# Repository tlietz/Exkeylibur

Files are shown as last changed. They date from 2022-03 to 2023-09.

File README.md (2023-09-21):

# Exkeylibur

```markdown
I froze your switches and made Exkeylibur,
and pushed it onto Github forever.
It stays there like Excalibur,
Are you its Arthur?
Say you are.

Take the cool, dark, steeled board,
Steal it, sheath it, in your workflow.
All would drown their other keebs to be together.
Must they breathe? 'Cause typing feels like heaven.
```

*Based off of ['Excalibur' - by David Brent](https://www.youtube.com/watch?v=634TC7Feku4)*

I would like to thank the honorable [Ferris Sweep](https://github.com/davidphilipbarr/Sweep), for without you, the Exkeylibur would have no pcb layout.

## Prelude

An Exkeylibur is a 36-key, diodeless, wireless-only keyboard with Ferris stagger and a reversible PCB.

An Exkeylibur can be wielded without a sheath, however, you are encouraged to create one.

A promicro, or any other non-wireless microcontroller drop-in for the promicro, is **not** supported. This is because the GPIO pin that would normally go to a TRRS jack
now goes to an extra switch.

## Features

- Wireless only
- No diodes required
- 36 keys
- Reversible PCB
- Ferris stagger
- Choc-spaced

## V2 Changes

- Rotated outer thumb key by 90 degrees to support 1.5u keycap
- Added room to place rubber feet
- Moved home thumb key to be between the two thumb keys of the Ferris Sweep
- Placed reset button in a position that can be easily pressed with finger
- Slightly increased reset button pcb pad spacing to support more button sizes

## Firmware Build Instructions

Edit the `ZMK_PATH`, `MCU`, and `KEEB` variables in `Makefile`

If this is your first time, run `make pristine`.
Next time, you can just do `make`.

The `firmware/` directory will have the left and right firmware files.

The keymap here may change in the future.

## Images

### V2

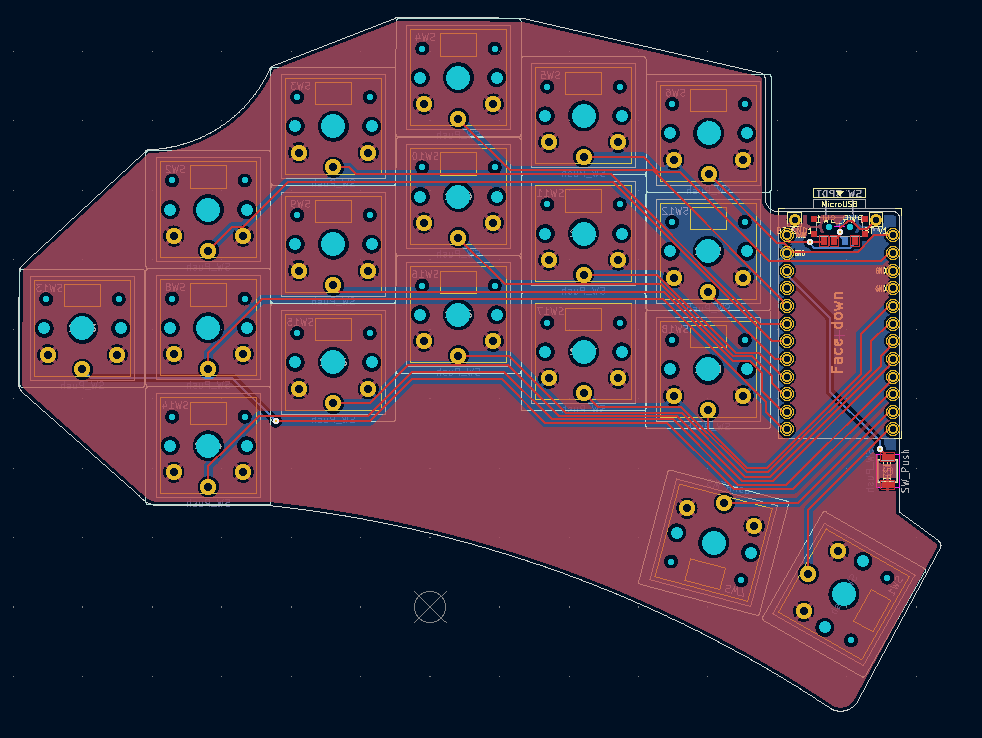
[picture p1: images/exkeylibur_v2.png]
v2


### V1

#### Original

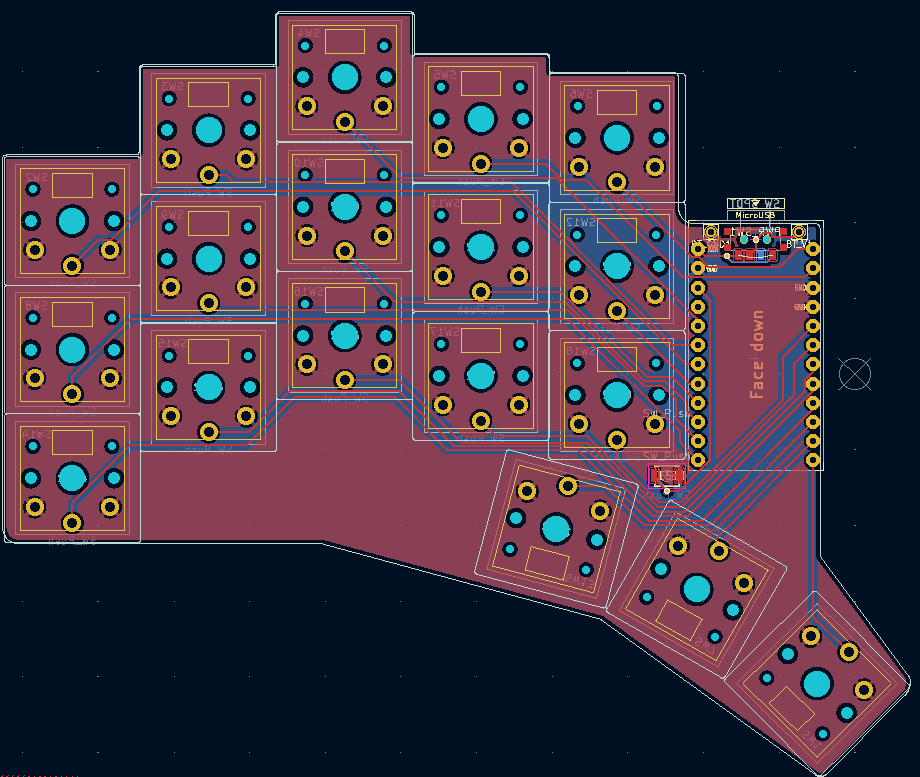
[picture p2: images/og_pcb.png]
original-pcb


#### Hilt

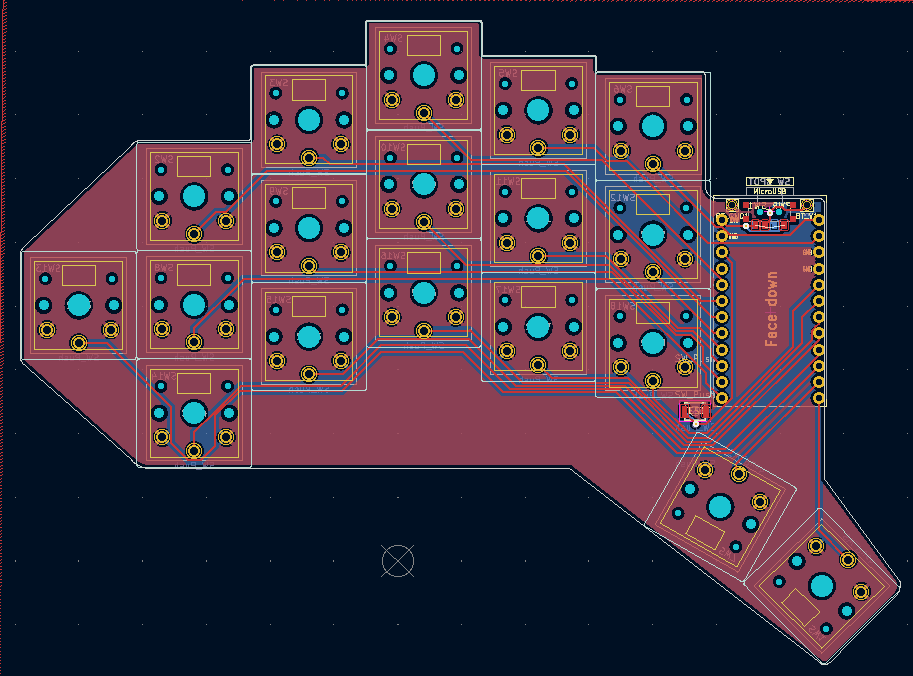
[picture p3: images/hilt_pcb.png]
hilt-pcb


#### Dagger

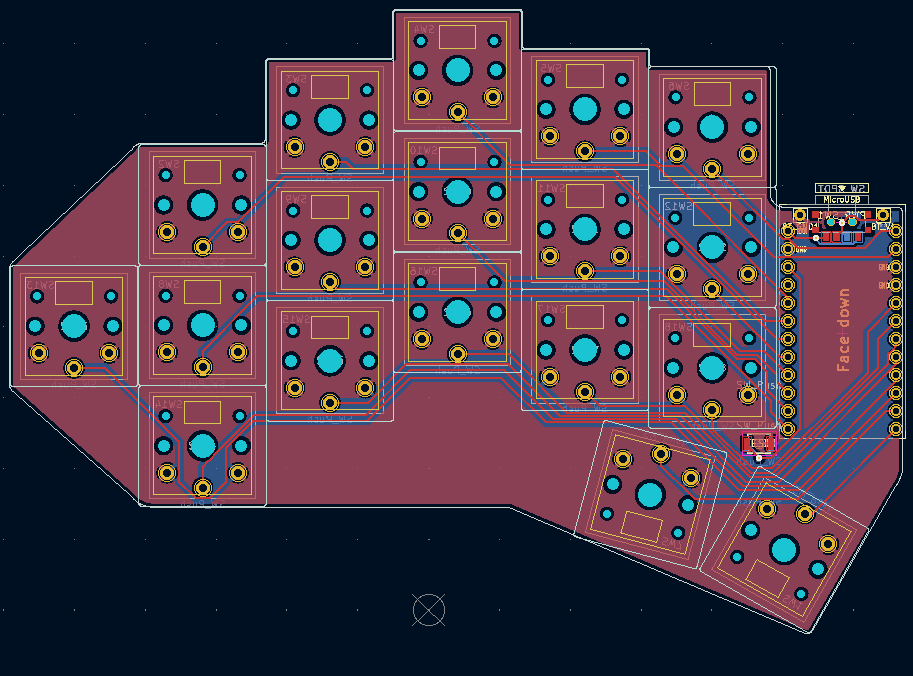
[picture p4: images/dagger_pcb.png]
dagger-pcb


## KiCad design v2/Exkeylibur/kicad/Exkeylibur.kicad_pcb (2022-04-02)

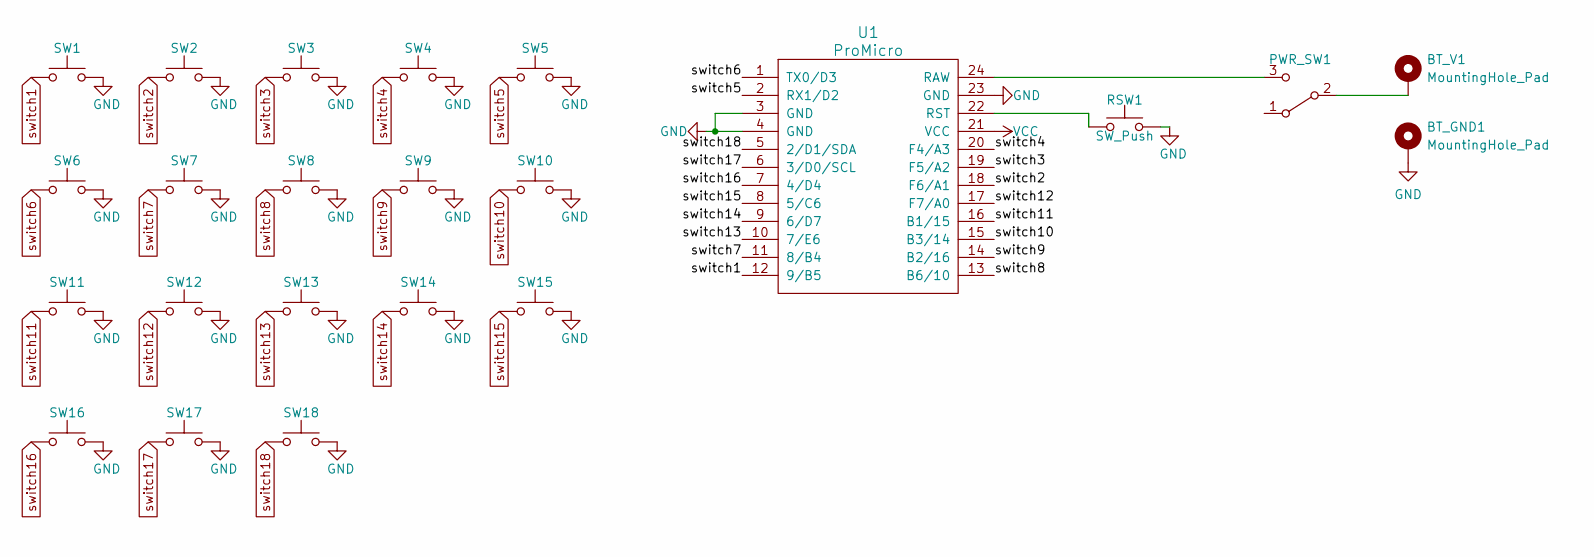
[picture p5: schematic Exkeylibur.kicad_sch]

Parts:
BT_GND1: MountingHole_Pad; bat_gnd_mountingHole
BT_V1: MountingHole_Pad; Bat_MountingHole
PWR_SW1: SW_SPDT; SPDT_C128955
RSW1: SW_Push; reset_switch
SW1, SW2, SW3, SW4, SW5, SW6, SW7, SW8, SW9, SW10, SW11, SW12, SW13, SW14, SW15, SW16, SW17, SW18: SW_Push; choc_switch_reversible
U1: ProMicro; ProMicro_v3_min

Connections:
GND: BT_GND1.1, RSW1.2, SW1.2, SW2.2, SW3.2, SW4.2, SW5.2, SW6.2, SW7.2, SW8.2, SW9.2, SW10.2, SW11.2, SW12.2, SW13.2, SW14.2, SW15.2, SW16.2, SW17.2, SW18.2, U1.3 (GND), U1.4 (GND), U1.23 (GND); also elsewhere on the board
unnamed 1: BT_V1.1, PWR_SW1.2 (B); also elsewhere on the board
unnamed 2: PWR_SW1.3 (C), U1.24 (RAW); also elsewhere on the board
unnamed 3: RSW1.1, U1.22 (RST); also elsewhere on the board
VCC: U1.21 (VCC)
switch1: SW1.1, U1.12 (9/B5)
switch2: SW2.1, U1.18 (F6/A1)
switch3: SW3.1, U1.19 (F5/A2)
switch4: SW4.1, U1.20 (F4/A3)
switch5: SW5.1, U1.2 (RX1/D2)
switch6: SW6.1, U1.1 (TX0/D3)
switch7: SW7.1, U1.11 (8/B4)
switch8: SW8.1, U1.13 (B6/10)
switch9: SW9.1, U1.14 (B2/16)
switch10: SW10.1, U1.15 (B3/14)
switch11: SW11.1, U1.16 (B1/15)
switch12: SW12.1, U1.17 (F7/A0)
switch13: SW13.1, U1.10 (7/E6)
switch14: SW14.1, U1.9 (6/D7)
switch15: SW15.1, U1.8 (5/C6)
switch16: SW16.1, U1.7 (4/D4)
switch17: SW17.1, U1.6 (3/D0/SCL)
switch18: SW18.1, U1.5 (2/D1/SDA)

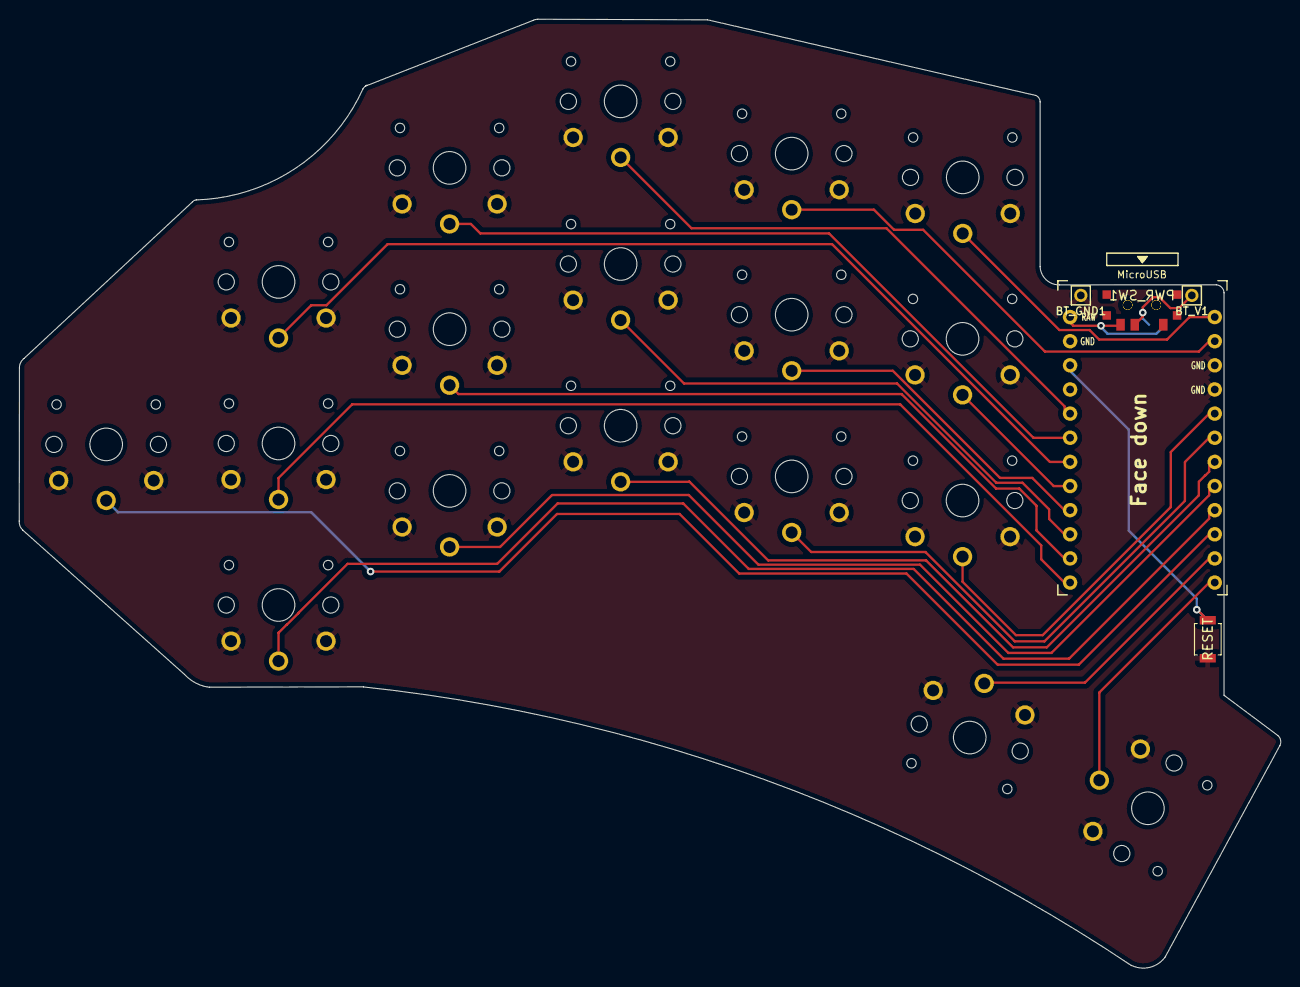
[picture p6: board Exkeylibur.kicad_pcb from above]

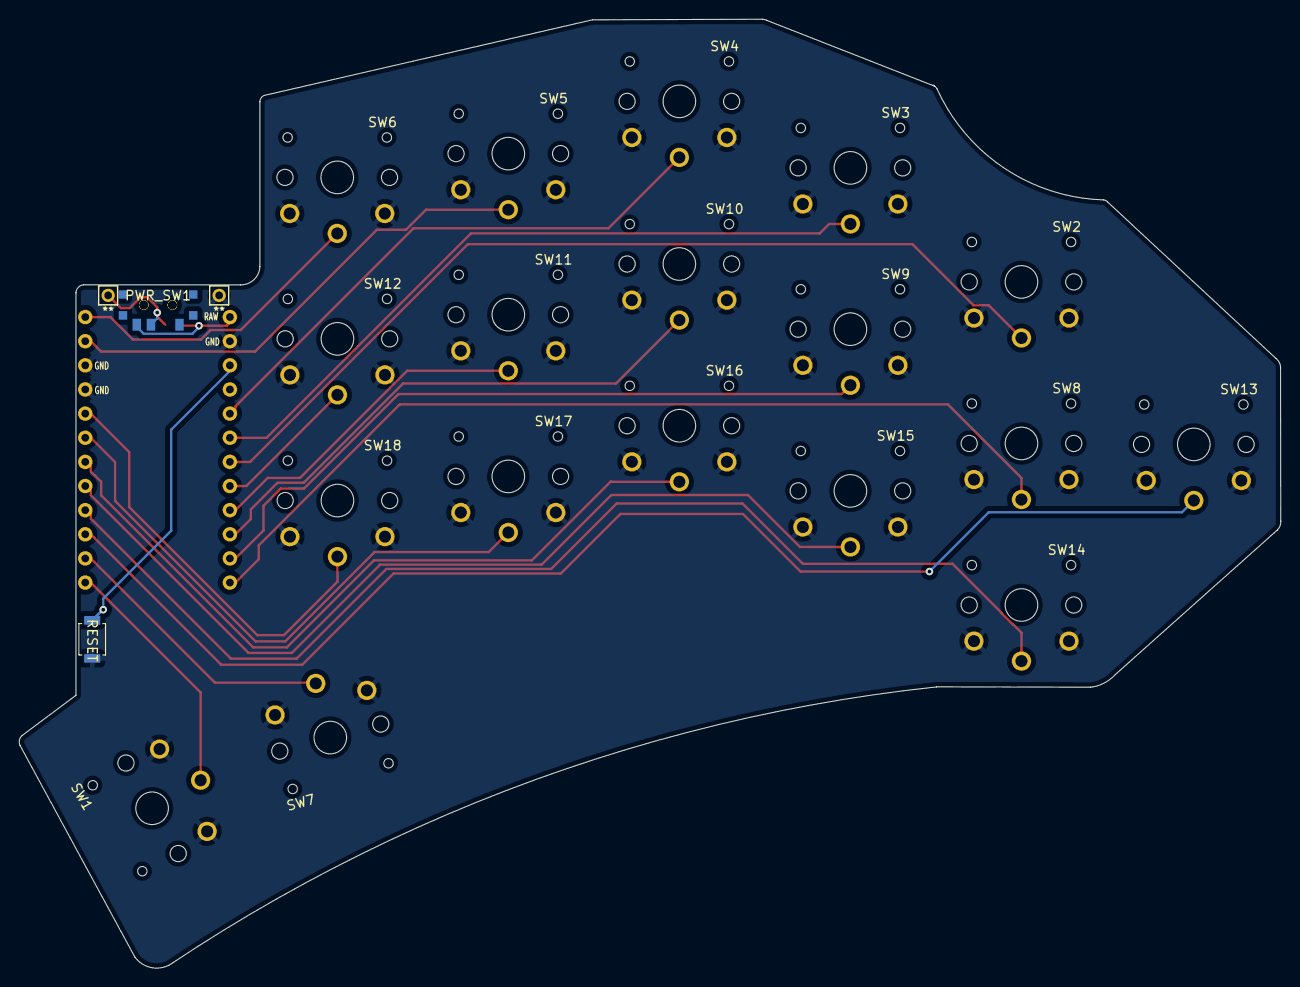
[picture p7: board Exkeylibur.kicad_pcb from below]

Board: 2 copper layers, 132.8 x 99.9 mm, 25 parts (2 on the bottom side), 22 nets.

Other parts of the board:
PWR_SW1#2: SW_SPDT; SPDT_C128955
RSW1#2: SW_Push; reset_switch

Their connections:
GND: RSW1#2.2; also elsewhere on the board
unnamed 1: PWR_SW1#2.2 (B); also elsewhere on the board
unnamed 2: PWR_SW1#2.3 (C); also elsewhere on the board
unnamed 3: RSW1#2.1; also elsewhere on the board

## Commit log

2022-02-24 eliteC TRRS and switches left side on schematic
    [Exkeylibur.kicad_sch]
2022-02-24 typo fix on switch ref des
    [Exkeylibur.kicad_sch]
2022-02-25 connect OLED to MC
    [Exkeylibur.kicad_sch]
2022-02-25 make right side schematic
    [Exkeylibur.kicad_sch]
2022-02-25 add no connects
    [Exkeylibur.kicad_sch]
2022-02-25 add annotations for left and right
    [Exkeylibur.kicad_sch]
2022-02-25 revert pcb
2022-03-02 changes outlay to include 4 thumb keys
    [Exkeylibur.kicad_sch]
2022-03-03 rework schematic to be compatible with promicro only
    [sweepv2.1.kicad_pcb]
2022-03-03 pcb reversible layout
    [Exkeylibur.kicad_pcb, Exkeylibur.kicad_sch, sweepv2.1.kicad_pcb]
2022-03-04 traces routed
    [Exkeylibur.kicad_pcb]
2022-03-04 copper pour
    [Exkeylibur.kicad_pcb]
2022-03-04 backannotate to schematic:
    [Exkeylibur.kicad_sch]
2022-03-04 save pcb
    [Exkeylibur.kicad_pcb]
2022-03-04 gerber zipped and repo structure in place
    [Exkeylibur-B_Cu.gbr, Exkeylibur-B_Mask.gbr, Exkeylibur-B_Paste.gbr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]
2022-03-04 create hilted and compressed versions of exkeylibur
    [Exkeylibur-B_Cu.gbr, Exkeylibur-B_Mask.gbr, Exkeylibur-B_Paste.gbr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]
2022-03-05 fix some errors with the board outline
    [Exkeylibur-B_Cu.gbr, Exkeylibur-B_Mask.gbr, Exkeylibur-B_Paste.gbr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]
2022-03-06 add images
    [Exkeylibur-B_Cu.gbr, Exkeylibur-B_Mask.gbr, Exkeylibur-B_Paste.gbr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]
2022-03-06 fix hilt pcb image link
2022-03-18 add more to readme, and organize v1 projects
    [Exkeylibur-B_Cu.gbr, Exkeylibur-B_Mask.gbr, Exkeylibur-B_Paste.gbr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]
2022-03-19 finish v2
    [Exkeylibur-B_Cu.gbr, Exkeylibur-B_Mask.gbr, Exkeylibur-B_Paste.gbr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]
2022-03-19 compress new gerber
2022-03-19 add more room for the 1.5u keycap
    [Exkeylibur-B_Cu.gbr, Exkeylibur-B_Mask.gbr, Exkeylibur-B_Paste.gbr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]
2022-04-02 fix grounding issue with one of the switches
    [Exkeylibur-B_Cu.gbr, Exkeylibur-B_Mask.gbr, Exkeylibur-B_Paste.gbr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]
